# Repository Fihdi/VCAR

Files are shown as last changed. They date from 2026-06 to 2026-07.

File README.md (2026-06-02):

# 8hp Voltage Controlled Attack Release / Slew Rate Limiter

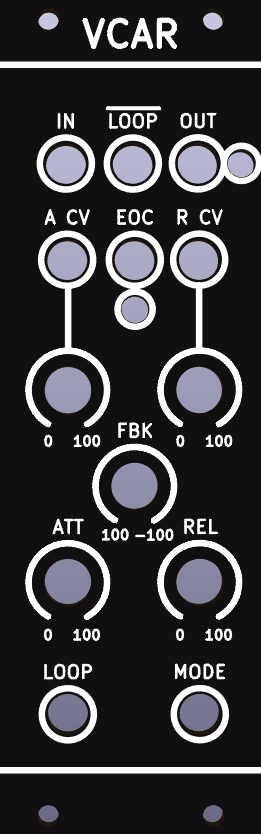
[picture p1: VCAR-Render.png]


VCAR is based on the Serge Dual Universal Slope Generator (DUSG). In Envelope mode, VCAR acts as an Attack-Release Envelope. With the LOOP switch engaged, the AR Envelope cycles indefinitely, allowing for VCO or LFO usage depending on the rate set by the Attack and Release settings. The looping can be stopped with an active Gate being present at the LOOP inhibit input. In Slew mode the output follows the input with a limited slew rate.

Use cases include Envelope Follower, Gate Delay, LFO/VCO, VCA, Wave Shaper, AR-Envelope, AHR-Envelope, Gate to Trigger Converter.

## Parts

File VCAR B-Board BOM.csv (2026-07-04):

Reference | Qty | Value | DNP | Exclude from BOM | Exclude from Board | Footprint | Datasheet
C1 | 1 | 10n |  |  |  | Capacitor_SMD:C_1206_3216Metric | ~
C2 | 1 | 100n |  |  |  | Capacitor_SMD:C_1206_3216Metric | ~
D1,D3,D4,D5,D6,D14,D15 | 7 | 1N4148 |  |  |  | Diode_SMD:D_SOD-323_HandSoldering | ~
J15 | 1 | Conn_02x05_Odd_Even |  |  |  | Connector_IDC:IDC-Header_2x05_P2.54mm_Vertical | ~
J102 | 1 | Conn_01x11_Pin |  |  |  | Connector_PinSocket_2.54mm:PinSocket_1x11_P2.54mm_Vertical | ~
Q1,Q3 | 2 | BC857 |  |  |  | Package_TO_SOT_SMD:SOT-23 | https://www.onsemi.com/pub/Collateral/BC860-D.pdf
Q2,Q4 | 2 | BC847 |  |  |  | Package_TO_SOT_SMD:SOT-23 | http://www.infineon.com/dgdl/Infineon-BC847SERIES_BC848SERIES_BC849SERIES_BC850SERIES-DS-v01_01-en.pdf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
R1,R2,R6,R8,R14 | 5 | 10k |  |  |  | Resistor_SMD:R_1206_3216Metric | ~
R3,R4,R5,R7,R15,R17,R24,R26,R27,R28,R29,R30 | 12 | 100k |  |  |  | Resistor_SMD:R_1206_3216Metric | ~
R12 | 1 | 2k2 |  |  |  | Resistor_SMD:R_1206_3216Metric | ~
R13 | 1 | 47k |  |  |  | Resistor_SMD:R_1206_3216Metric | ~
R25,R35 | 2 | 27k |  |  |  | Resistor_SMD:R_1206_3216Metric | ~
R36,R37 | 2 | 1k |  |  |  | Resistor_SMD:R_1206_3216Metric | ~
U3 | 1 | 4001 |  |  |  | Package_SO:SO-14_3.9x8.65mm_P1.27mm | http://www.intersil.com/content/dam/Intersil/documents/cd40/cd4000bms-01bms-02bms-25bms.pdf
U5,U6 | 2 | TL074 |  |  |  | Package_SO:SO-14_3.9x8.65mm_P1.27mm | http://www.ti.com/lit/ds/symlink/tl071.pdf

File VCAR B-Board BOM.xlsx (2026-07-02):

 |  |  | VCAR B-Board BOM
Item # | *Designator | *Qty | Manufacturer | *Mfg Part # | Description / Value | *Package/Footprint | Type | Your Instructions / Notes
1 | C1 | 1 |  | C107192 | 10n | Capacitor_SMD:C_1206_3216Metric
2 | C2 | 1 |  | C82601 | 100n | Capacitor_SMD:C_1206_3216Metric
3 | D1,D3,D4,D5,D6,D14,D15 | 7 |  | C917117 | 1N4148 | Diode_SMD:D_SOD-323_HandSoldering
4 | J15 | 1 |  |  | Conn_02x05_Odd_Even | Connector_IDC:IDC-Header_2x05_P2.54mm_Vertical |  | DNP
5 | J102 | 1 |  |  | Conn_01x11_Pin | Connector_PinSocket_2.54mm:PinSocket_1x11_P2.54mm_Vertical |  | DNP
6 | Q1,Q3 | 2 |  | C148244 | BC857 | Package_TO_SOT_SMD:SOT-23
7 | Q2,Q4 | 2 |  | C3200107 | BC847 | Package_TO_SOT_SMD:SOT-23
8 | R1,R2,R6,R8,R14 | 5 |  | C136889 | 10k | Resistor_SMD:R_1206_3216Metric
9 | R3,R4,R5,R7,R15,R17,R24,R26,R27,R28,R29,R30 | 12 |  | C728669 | 100k | Resistor_SMD:R_1206_3216Metric
10 | R12 | 1 |  | C114933 | 2k2 | Resistor_SMD:R_1206_3216Metric
11 | R13 | 1 |  | C870758 | 47k | Resistor_SMD:R_1206_3216Metric
12 | R25,R35 | 2 |  | C844427 | 27k | Resistor_SMD:R_1206_3216Metric
13 | R36,R37 | 2 |  | C131398 | 1k | Resistor_SMD:R_1206_3216Metric
14 | U3 | 1 |  | C49967 | CD4001 | Package_SO:SO-14_3.9x8.65mm_P1.27mm
15 | U5,U6 | 2 |  | C12594 | TL074 | Package_SO:SO-14_3.9x8.65mm_P1.27mm
Need a quick and accurante quote? Need an efficient production? Please read SMT Ordering Necessary Files & Info in 1 minute. Thank you very much!
Click for Instructions on How to Create a BOM (https://www.pcbway.com/blog/PCB_Assembly/How_to_Build_a_BOM__Bill_Of_Materials_.html)

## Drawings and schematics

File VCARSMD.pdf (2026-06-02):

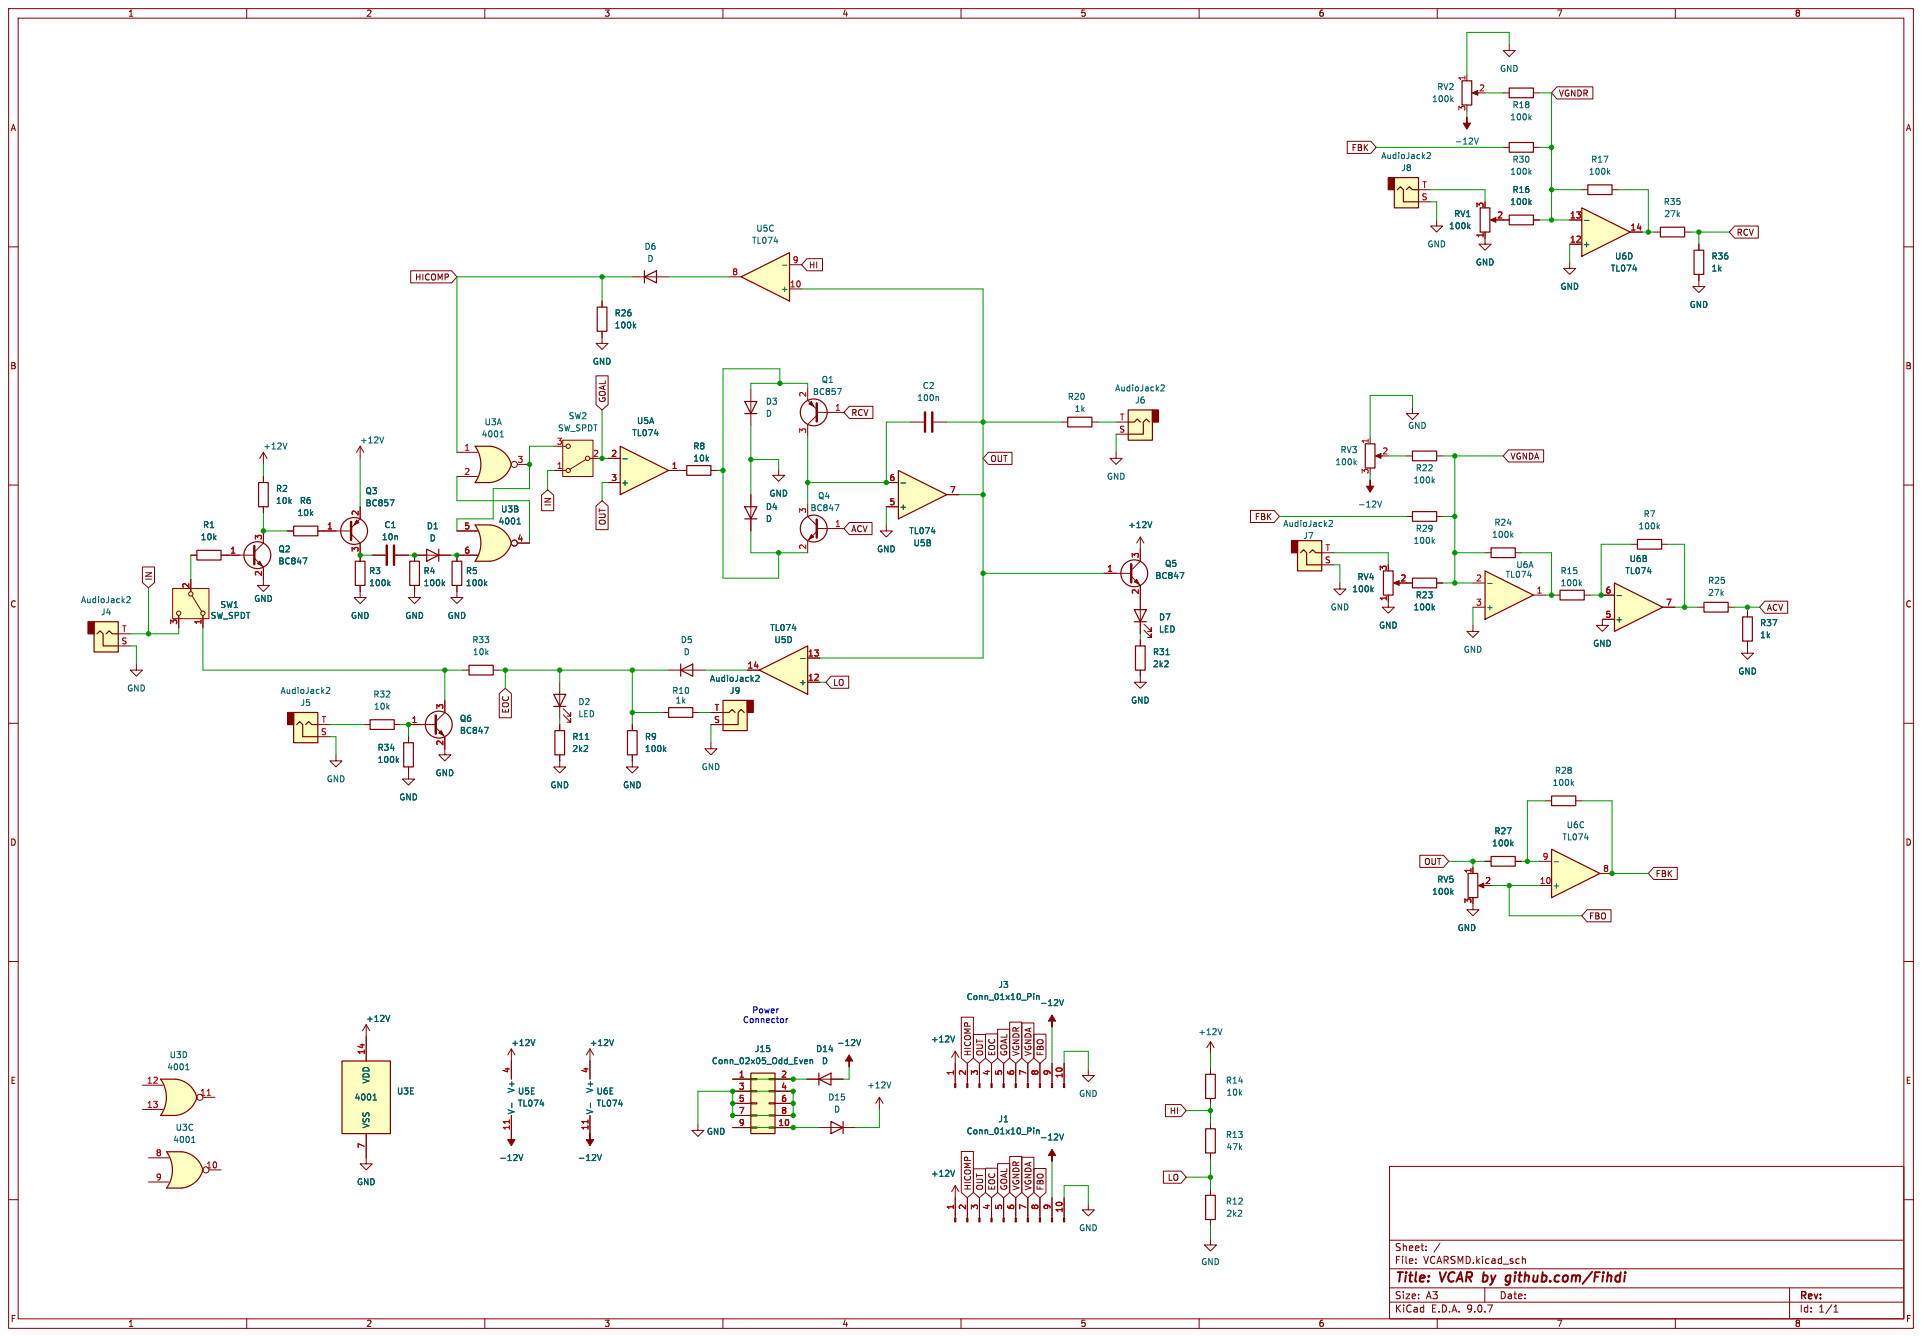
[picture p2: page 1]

Id: 1/1 Title: VCAR by github.com/Fihdi File: VCARSMD.kicad_sch Sheet: / +12V

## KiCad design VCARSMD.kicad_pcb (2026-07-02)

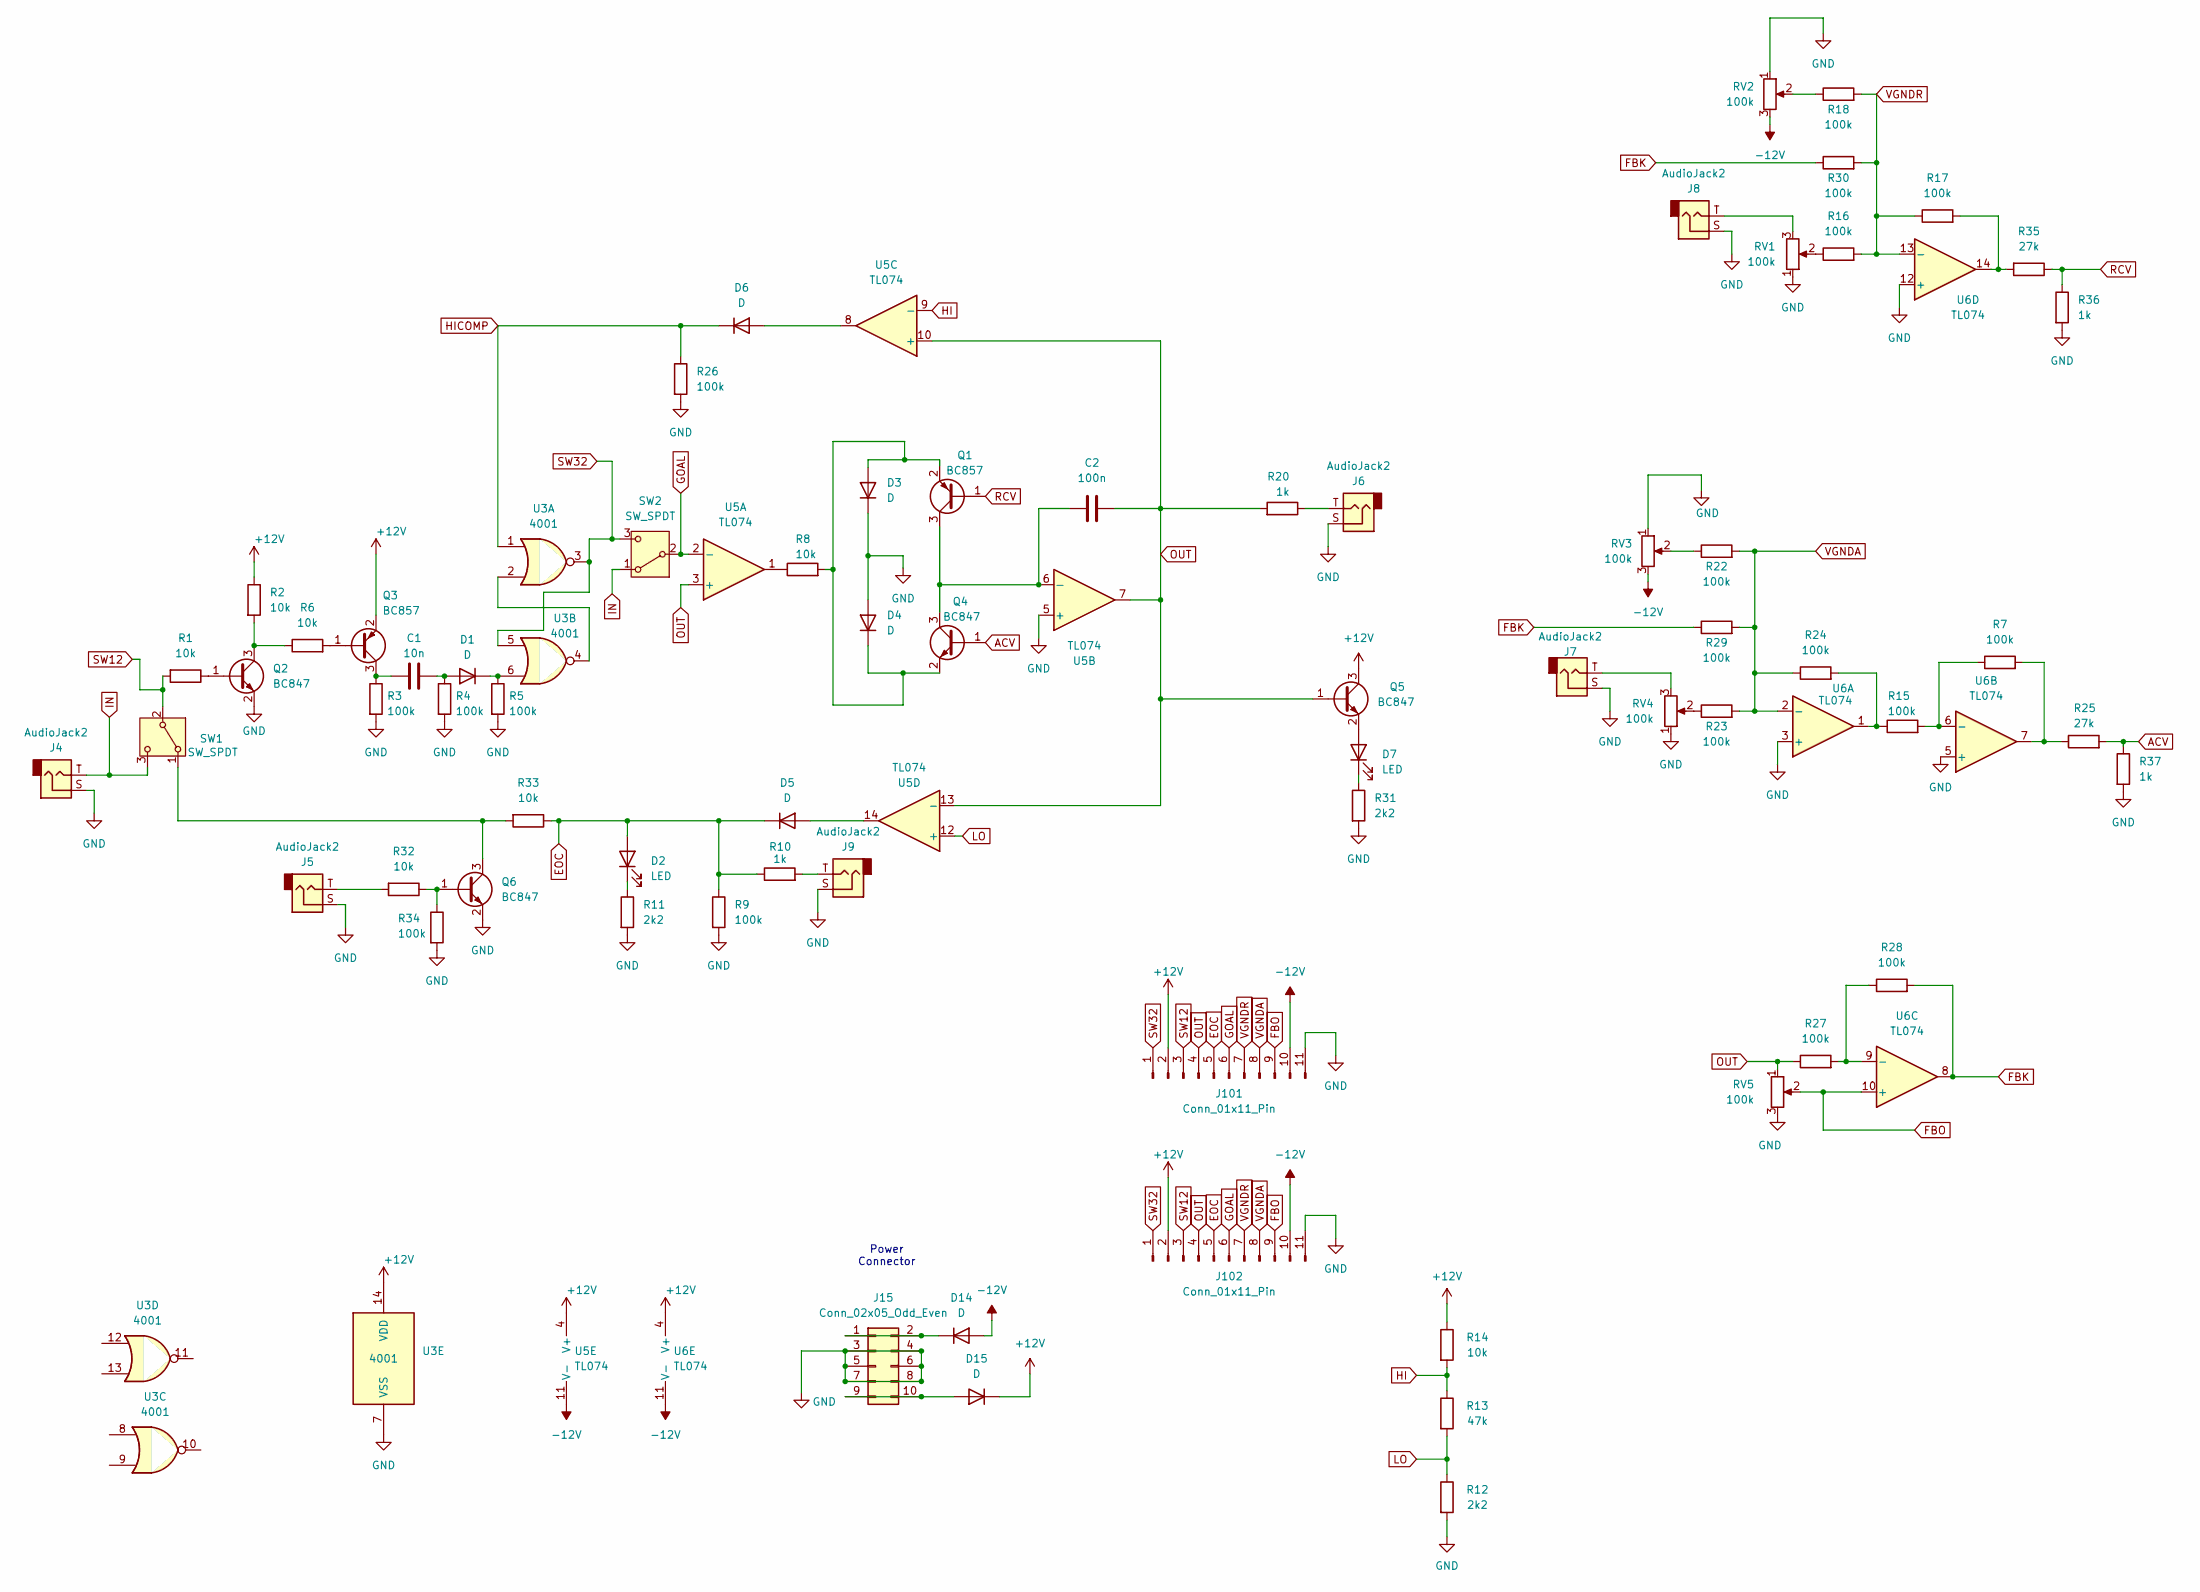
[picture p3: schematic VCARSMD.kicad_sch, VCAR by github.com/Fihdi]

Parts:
C1: 10n; C_1206_3216Metric
C2: 100n; C_1206_3216Metric
D1, D3, D4, D5, D6, D14, D15: D; D_SOD-323_HandSoldering
D2, D7: LED; LED_D3.0mm
J4, J5, J6, J7, J8, J9: AudioJack2; MonoTRS
J15: Conn_02x05_Odd_Even; IDC-Header_2x05_P2.54mm_Vertical
J101, J102: Conn_01x11_Pin; PinSocket_1x11_P2.54mm_Vertical
Q1, Q3: BC857; SOT-23
Q2, Q4, Q5, Q6: BC847; SOT-23
R1, R2, R6, R8, R14, R32, R33: 10k; R_1206_3216Metric
R3, R4, R5, R7, R9, R15, R16, R17, R18, R22, R23, R24, R26, R27, R28, R29, R30, R34: 100k; R_1206_3216Metric
R10, R20, R36, R37: 1k; R_1206_3216Metric
R11, R12, R31: 2k2; R_1206_3216Metric
R13: 47k; R_1206_3216Metric
R25, R35: 27k; R_1206_3216Metric
RV1, RV2, RV3, RV4, RV5: 100k; Potentiometer_Alpha_RD901F-40-00D_Single_Vertical
SW1, SW2: SW_SPDT; Switch
U3: 4001; SO-14_3.9x8.65mm_P1.27mm
U5, U6: TL074; SO-14_3.9x8.65mm_P1.27mm

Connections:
+12V: D15.1 (K), J101.2, J102.2, Q3.2 (E), Q5.3 (C), R2.1, R14.1, U3.14 (VDD), U5.4 (V+), U6.4 (V+)
-12V: D14.2 (A), J101.10, J102.10, RV2.3, RV3.3, U5.11 (V-), U6.11 (V-)
ACV: Q4.1 (B), R25.2, R37.1
EOC: D2.2 (A), D5.1 (K), J101.5, J102.5, R9.1, R10.1, R33.1
FBK: R28.2, R29.1, R30.1, U6.8
FBO: J101.9, J102.9, RV5.2, U6.10 (+)
GND: D3.1 (K), D4.2 (A), J4.S, J5.S, J6.S, J7.S, J8.S, J9.S, J15.3, J15.4, J15.5, J15.6, J15.7, J15.8, J101.11, J102.11, Q2.2 (E), Q6.2 (E), R3.2, R4.2, R5.2, R9.2, R11.2, R12.2, R26.2, R31.2, R34.2, R36.2, R37.2, RV1.1, RV2.1, RV3.1, RV4.1, RV5.3, U3.7 (VSS), U5.5 (+), U6.3 (+), U6.5 (+), U6.12 (+)
GOAL: J101.6, J102.6, SW2.2 (B), U5.2 (-)
HI: R13.1, R14.2, U5.9 (-)
HICOMP: D6.1 (K), R26.1, U3.1
IN: J4.T, SW1.3 (C), SW2.1 (A)
LO: R12.1, R13.2, U5.12 (+)
unnamed: C1.2, D1.2 (A), R4.1
unnamed: D1.1 (K), R5.1, U3.6
unnamed: D2.1 (K), R11.1
unnamed: D3.2 (A), D4.1 (K), Q1.2 (E), Q4.2 (E), R8.2
unnamed: D5.2 (A), U5.14
unnamed: D6.2 (A), U5.8
unnamed: D7.2 (A), Q5.2 (E)
unnamed: D7.1 (K), R31.1
unnamed: D14.1 (K), J15.1, J15.2
unnamed: D15.2 (A), J15.9, J15.10
unnamed: J5.T, R32.2
unnamed: J6.T, R20.1
unnamed: J7.T, RV4.3
unnamed: J8.T, RV1.3
unnamed: J9.T, R10.2
unnamed: C2.1, Q1.3 (C), Q4.3 (C), U5.6 (-)
unnamed: Q2.1 (B), R1.1
unnamed: Q2.3 (C), R2.2, R6.1
unnamed: Q3.1 (B), R6.2
unnamed: C1.1, Q3.3 (C), R3.1
unnamed: Q6.1 (B), R32.1, R34.1
unnamed: Q6.3 (C), R33.2, SW1.1 (A)
unnamed: R8.1, U5.1
unnamed: R15.1, R24.2, U6.1
unnamed: R16.1, RV1.2
unnamed: R17.2, R35.2, U6.14
unnamed: R18.1, RV2.2
unnamed: R22.1, RV3.2
unnamed: R23.1, RV4.2
unnamed: R7.2, R25.1, U6.7
unnamed: U3.2, U3.4
unnamed: R7.1, R15.2, U6.6 (-)
unnamed: R27.2, R28.1, U6.9 (-)
OUT: C2.2, J101.4, J102.4, Q5.1 (B), R20.2, R27.1, RV5.1, U5.3 (+), U5.7, U5.10 (+), U5.13 (-)
RCV: Q1.1 (B), R35.1, R36.1
SW12: J101.3, J102.3, R1.2, SW1.2 (B)
SW32: J101.1, J102.1, SW2.3 (C), U3.3, U3.5
VGNDA: J101.8, J102.8, R22.2, R23.2, R24.1, R29.2, U6.2 (-)
VGNDR: J101.7, J102.7, R16.2, R17.1, R18.2, R30.2, U6.13 (-)

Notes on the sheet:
Power Connector

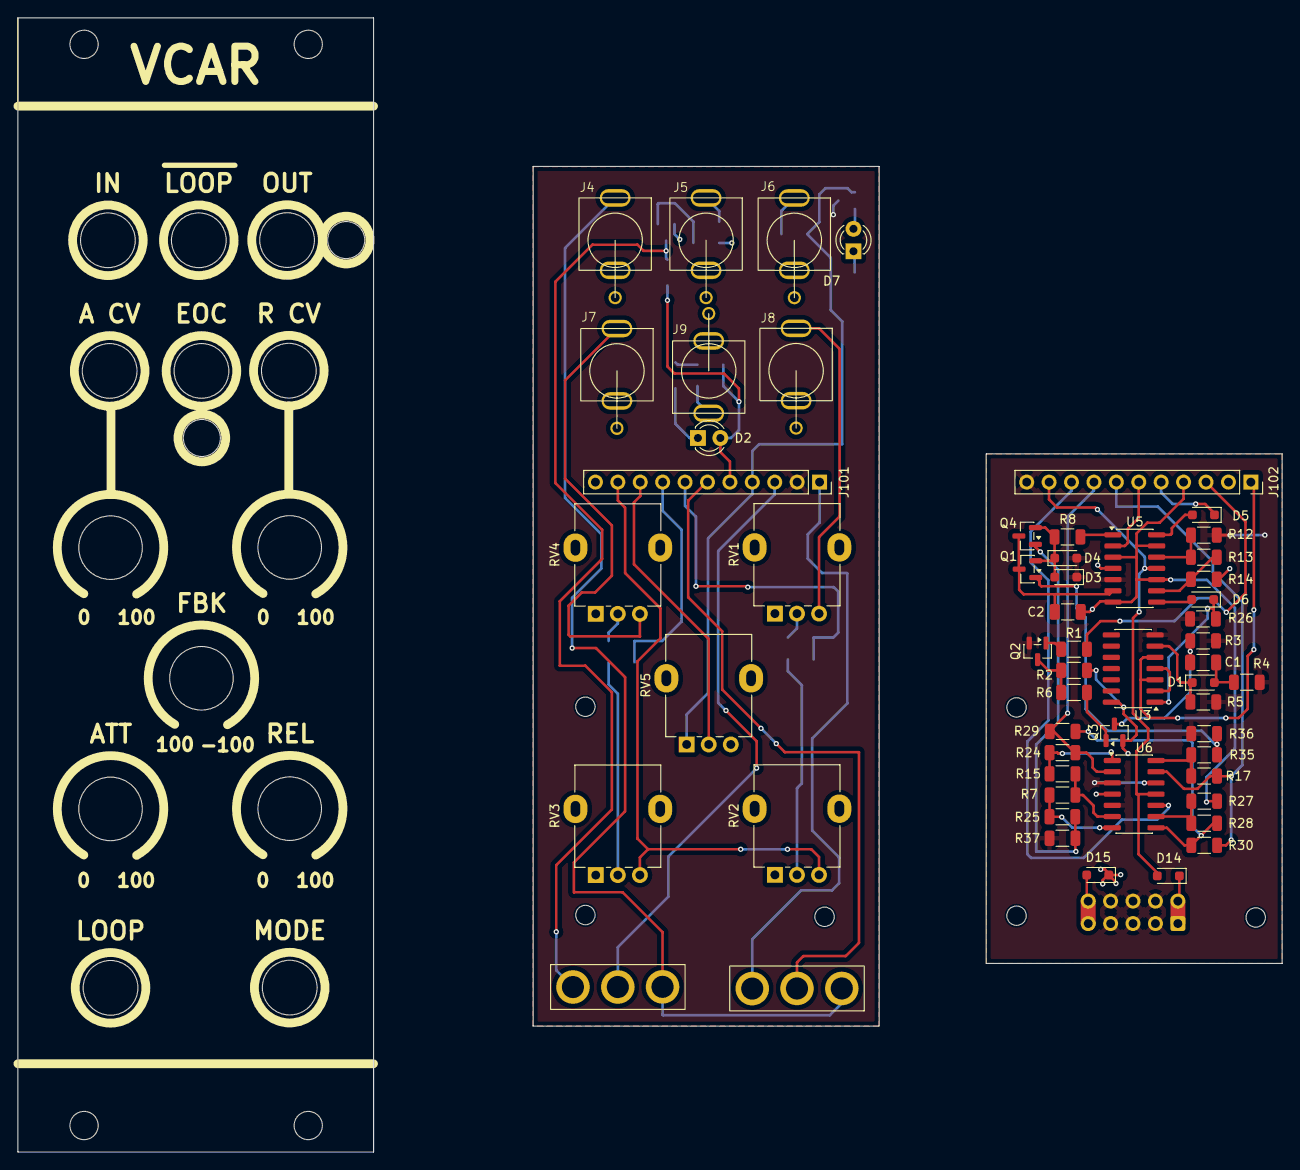
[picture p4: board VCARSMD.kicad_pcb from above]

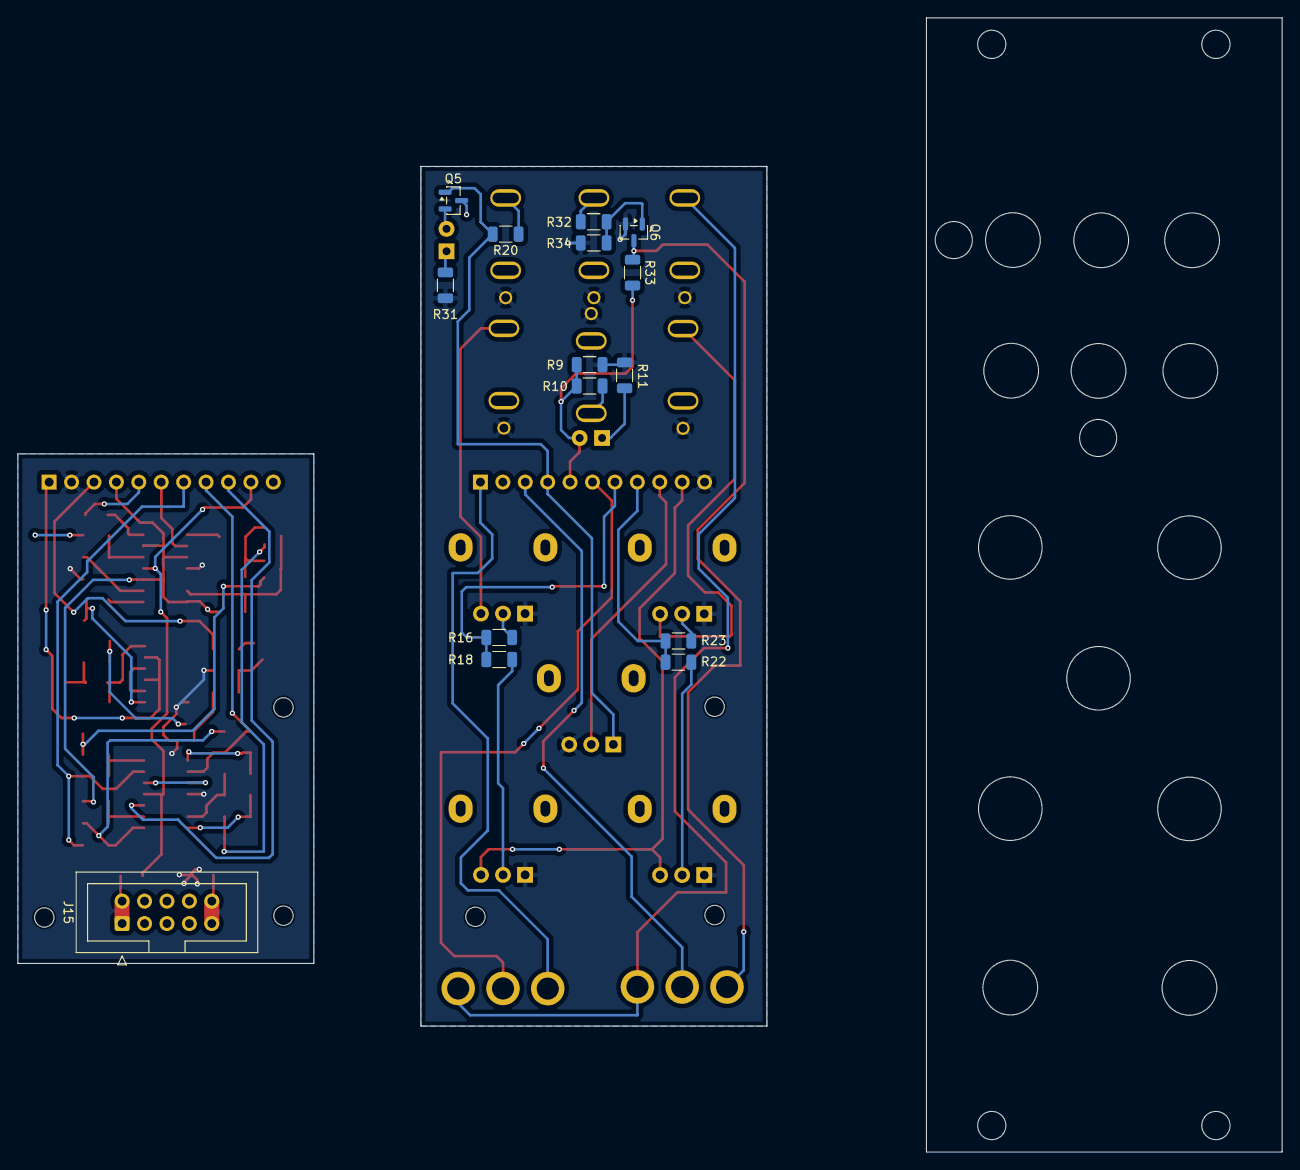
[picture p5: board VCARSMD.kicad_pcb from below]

Board: 2 copper layers, 143.2 x 128.5 mm, 71 parts (15 on the bottom side), 51 nets.
